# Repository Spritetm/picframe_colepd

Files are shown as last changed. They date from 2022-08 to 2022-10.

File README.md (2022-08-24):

* Workflow
Uploading:
- html/js: select image, crop, resize, upload to server
- upload php: use C program to convert to EPD.
  Spit out preview (?), add epd to database w/ timestamp

epd:
- Wake up
If Internet:
 * fetch index JSON file (contains OTA plus timestamps of last 10 images)
 * Update files to make internal store match 
 * Update list of image shows: set to 0 for new images
- Take list of image shows; get lowest show count; show newest image with that count.

Flash:
Other shit: 0x10000
OTA1: 0x150000
OTA2: 0x150000
left: 0x150000

img size 134464
11 images -> 10 150000

Case uses M3 inserts: height 4mm dia 5mm
Corresponding screws: M3*6mm

Colors:
- Grab picture in 'normal' situation (daylight, curtains, ...)
- Open in Gimp
- Image -> precision: 16-bit, linear
- Filters -> blur (to get rid of grain)
- Curve -> make darker colors a bit more dark (so it mixes more white in there, making end image lighter)
- Filters -> levels, select black level, select white level

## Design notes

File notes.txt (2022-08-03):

For PCB:
XR1151 - 800'ish mA, 65uA quiescent -> 3.5 year
ESP32C3 - need to test if works with same code, otherwise NP

Article:
Color Floyd-Steinberg is a PITA. Difference colors? LAB colors, euclidian thingy. That sucks,
pink white and blue-ish white is the same difference as red and blue. Initial modification:
multiply A and B differences (=hue difference) with sin(L). This makes those differences less
important. Great results. But WtF is up with the shitty 'official' way? Seems there's multiple
ways: latest and greatest is E2000. Actually not that much different than my hacky solution.

Non-linear color space: one pixel of (0,0,0) and one of (64,64,64) don't look the same 
(are not as bright) as two of (32,32,32). Luckily (linearized) RGB works.

Stucki dithering?

https://mathematica.stackexchange.com/questions/7483/how-to-calculate-mix-of-4-colors-defined-in-cielab-lab-model

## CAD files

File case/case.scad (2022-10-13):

/*
 * ----------------------------------------------------------------------------
 * "THE BEER-WARE LICENSE" (Revision 42):
 * Jeroen Domburg <jeroen@spritesmods.com> wrote this file. As long as you retain 
 * this notice you can do whatever you want with this stuff. If we meet some day, 
 * and you think this stuff is worth it, you can buy me a beer in return. 
 * ----------------------------------------------------------------------------
*/


$fs=0.2;

pcb_size=[155.5,130,1.6];
holes=[
    [7.5,7.5,0],
    [7.5,65,0],
    [7.5,130-7.5,0],
    [155.5-40.1,7.5,0],
    [155.5-7.5,65,0],
    [155.5-7.5,130-7.5,0],
    [155.5/2,130+5.3,0] //battery compartment screw
];
btns=[
    [64, 92.25, 0],
    [91.5, 92.25, 0]
];
btn_d=10;

//location of the battery terminals
bat_plus_pos=[24.5, 122, 0];
bat_min_pos=[131, 122, 0];
//Size of the pocket for the battery terminal solder points
bat_term_stickout=[3, 6, 1.3];
bat_term_size=[0.65, 12, 12.5];
bat_dia=15; //aa battery
eink_pcb_offset=[16.2, 16.9, 0];
eink_size=[125.4, 99.5, 0.95];
eink_vis_size=[114.9, 85.8, 0]; //visible area size
eink_vis_offset=[5.25, eink_size.y-eink_vis_size.y-4.6, 0];

pcb_center=eink_pcb_offset+eink_vis_offset+eink_vis_size/2;

mat_size=[145,120,3]; //size of actual mat
mat_cutout=[eink_vis_size.x+15, eink_vis_size.y+15,0]; //cutout for mat in case
mat_vis_extra=1; //how much mm more to show than the visible eink area

case_size=[170,143,24];
case_th=1.5;

screw_insert_d=5;
screw_insert_h=4;
screw_insert_post_d=7;
screw_hole_d=8.5;
screw_thread_hole_d=3.5;

tolerance=0.2;

support_d=2.0+tolerance;
support_pos=[0,-30,-6];
support_angle=[30,0,0];

render=2;

if (render==1) {
    intersection() {
        rotate([0,0,00]) union() {
            translate(-pcb_center) pcb();
            translate([0,0,pcb_size.z]) color("beige") mat();
            case_top();
            case_bottom();
            battery_lid();
        }
        translate([0,55,0])cube([200,1,40], center=true);
    }
} else if (render==2) {
    //translate(-pcb_center) pcb();
    //translate([0,0,pcb_size.z]) color("beige") mat();
    //case_top();
    case_bottom();
    //battery_lid();
} else if (render==3) {
    button("R");
    translate([10,10,0]) button("C");
}


module button(txt) {
    difference() {
        union() {
            cylinder(h=8, d=btn_d-tolerance*2);
            cylinder(h=2, d=btn_d+case_th*2);
            translate([-(case_th-tolerance*2)/2,0,0]) cube([(case_th-tolerance*2),btn_d/2+case_th,5]);
        }
        translate([0,0,-1]) cylinder(h=3.5, d=4.5);
        translate([-3,-3,7.5])linear_extrude(height = 1) {
            text(txt, font = "Liberation Sans:style=Bold",size=6);
        }
    }
}

module pcb() {
    difference() {
        cube(pcb_size);
        for (pos=holes) {
            translate(pos+[0,0,-1]) cylinder(h=pcb_size.z+2, d=3.2);
        }
    }
    //Eink
    translate(eink_pcb_offset) color("white") cube(eink_size+[0,0,pcb_size.z]);
    //eink visible area
    translate(eink_pcb_offset+eink_vis_offset) color("magenta") cube(eink_vis_size+[0,0,pcb_size.z+eink_size.z+0.1]);
    translate(bat_plus_pos-[bat_term_size.x/2, bat_term_size.y/2, bat_term_size.z]) cube(bat_term_size);
    translate(bat_min_pos-[bat_term_size.x/2, bat_term_size.y/2, bat_term_size.z]) cube(bat_term_size);
    translate(bat_plus_pos-[-2, 0, bat_dia/2]) rotate([0,90,0]) cylinder(d=bat_dia, h=100);
}

module chamfered_cutout(size) {
    difference() {
    translate([0,0,size.z/2]) cube(size+[size.z*2,size.z*2,tolerance*2], center=true);
        translate([-size.x/2,-size.y,0]) rotate([0,-45,0]) translate([-size.z*2,0,0]) cube([size.z*2, size.y*2, size.z*2]);
        translate([size.x/2,-size.y,0]) rotate([0,45,0]) translate([0,0,-tolerance*2])cube([size.z*2, size.y*2, size.z*2]);
        translate([-size.x,-size.y/2,0]) rotate([45,0,0]) translate([0,-size.z*2,0])cube([size.x*2, size.z*2, size.z*2]);
        translate([-size.x,size.y/2,0]) rotate([-45,0,0]) translate([0,0,-tolerance*2])cube([size.x*2, size.z*2, size.z*2]);
    }
}


//note: assuming the eink visible middle is at [0,0] and the top of the pcb at z=0
module mat() {
    difference() {
        translate([0,0,mat_size.z/2]) cube(mat_size, center=true);
        for (pos=holes) {
            translate(-pcb_center+pos+[0,0,-1]) cylinder(h=mat_size.z+2, d=screw_insert_post_d+tolerance*2);
        }
        //beveled hole
        translate([0,0,eink_size.z-tolerance])chamfered_cutout(eink_vis_size+[mat_vis_extra*2,mat_vis_extra*2,mat_size.z]);
        //eink plate hole
        translate(-pcb_center+eink_pcb_offset-[1, 1, tolerance]) cube(eink_size+[1, 1, tolerance]*2);
        //cutouts for battery contact solder things
        translate(-pcb_center+bat_plus_pos-[bat_term_stickout.x/2, bat_term_stickout.y/2, pcb_size.z]) cube(bat_term_stickout+[0,0,pcb_size.z]);
        translate(-pcb_center+bat_min_pos-[bat_term_stickout.x/2, bat_term_stickout.y/2, tolerance]) cube(bat_term_stickout+[0,0,tolerance]);
    }
}


module case_top() {
    difference() {
        intersection() {
            case();
            translate([-100,-100,-case_th+tolerance*2]) cube([200,200,20]);
        }
        //lip
        translate([-case_size.x/2+case_th/2-tolerance/2, -case_size.y/2+case_th/2-tolerance/2, -case_size.z+tolerance*2]) cube(case_size-[case_th-tolerance,case_th-tolerance,0]);
    }
}


module case_bot_fancy(pullback) {
    edge_off=case_th*2;
    h=bat_dia+case_th*2;
    difference() {
        //square case
        translate([0,0,bat_dia/2+case_th-pullback]) cube([case_size.x-pullback*2,case_size.y-pullback*2,bat_dia+edge_off], center=true);
        //beveled main
        translate([-100, pcb_center.y-bat_plus_pos.y+bat_dia/2, h-pullback]) rotate([-5,0,0]) cube([200,200,20]);
        //beveled at battery
        translate([-100, pcb_center.y-bat_plus_pos.y-bat_dia/2, h-pullback]) rotate([30,0,0]) translate([0,-200,0]) cube([200,200,20]);
        //beveled edges
        translate([case_size.x/2,-case_size.y/2-tolerance,edge_off-pullback]) rotate([0,50,0]) translate([-100,-tolerance*2,0]) cube([100,case_size.y+tolerance*4,case_size.z,]);
        translate([-case_size.x/2,case_size.y/2-tolerance,edge_off-pullback]) rotate([0,50,180]) translate([-100,-tolerance*2,0]) cube([100,case_size.y+tolerance*4,case_size.z,]);

        //lip
        if (pullback==0) difference() {
            translate([0,0,case_th/2+tolerance/2]) cube([case_size.x,case_size.y,case_th+tolerance], center=true);
            translate([0,0,case_th/2+tolerance/2]) cube([case_size.x-case_th,case_size.y-case_th,case_th+tolerance], center=true);
        }
    }
}

module battery_lid_cutout(pullback) {
    translate(-pcb_center) {
        translate([bat_plus_pos.x-bat_term_size.x/2-pullback,bat_min_pos.y-bat_dia/2-pullback,-20+tolerance*(case_th-pullback)]) cube((bat_min_pos-bat_plus_pos)+[bat_term_size.x+pullback*2,50,20]);
        
    }
}


module battery_lid() {
    difference() {
        intersection() {
            difference() {
                //outer case
                rotate([180,0,0]) case_bot_fancy(0);
                //cut out screwholes
                for (pos=holes) {
                    translate(-pcb_center+pos+[0,0,-50-case_th]) cylinder(h=50, d=screw_hole_d);
                    translate(-pcb_center+pos+[0,0,-50+tolerance]) cylinder(h=50, d=screw_thread_hole_d);
                }
            }
            //cut out battery lid itself and half of the inner wall
            battery_lid_cutout(case_th/2-tolerance);
        }
        difference() {
            rotate([180,0,0]) case_bot_fancy(case_th/2-tolerance);
            battery_lid_cutout(-tolerance);
        }
        difference() {
            //inner case
            rotate([180,0,0]) case_bot_fancy(case_th);
            //cut out screwholes
            for (pos=holes) {
                translate(-pcb_center+pos+[0,0,-50]) cylinder(h=50, d=screw_hole_d+case_th*2);
            }
    translate(-pcb_center+[bat_plus_pos.x-bat_term_size.x,bat_min_pos.y+bat_dia/2,-20+tolerance]) cube((bat_min_pos-bat_plus_pos)+[bat_term_size.x*2,case_th,20]);

        }
    }
    
}

module support(pullback) {
    translate(support_pos) rotate(-support_angle+[270,0,0]) translate([0,0,-pullback]) cylinder(h=90,d=support_d+pullback*2);
}

//support(0);
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

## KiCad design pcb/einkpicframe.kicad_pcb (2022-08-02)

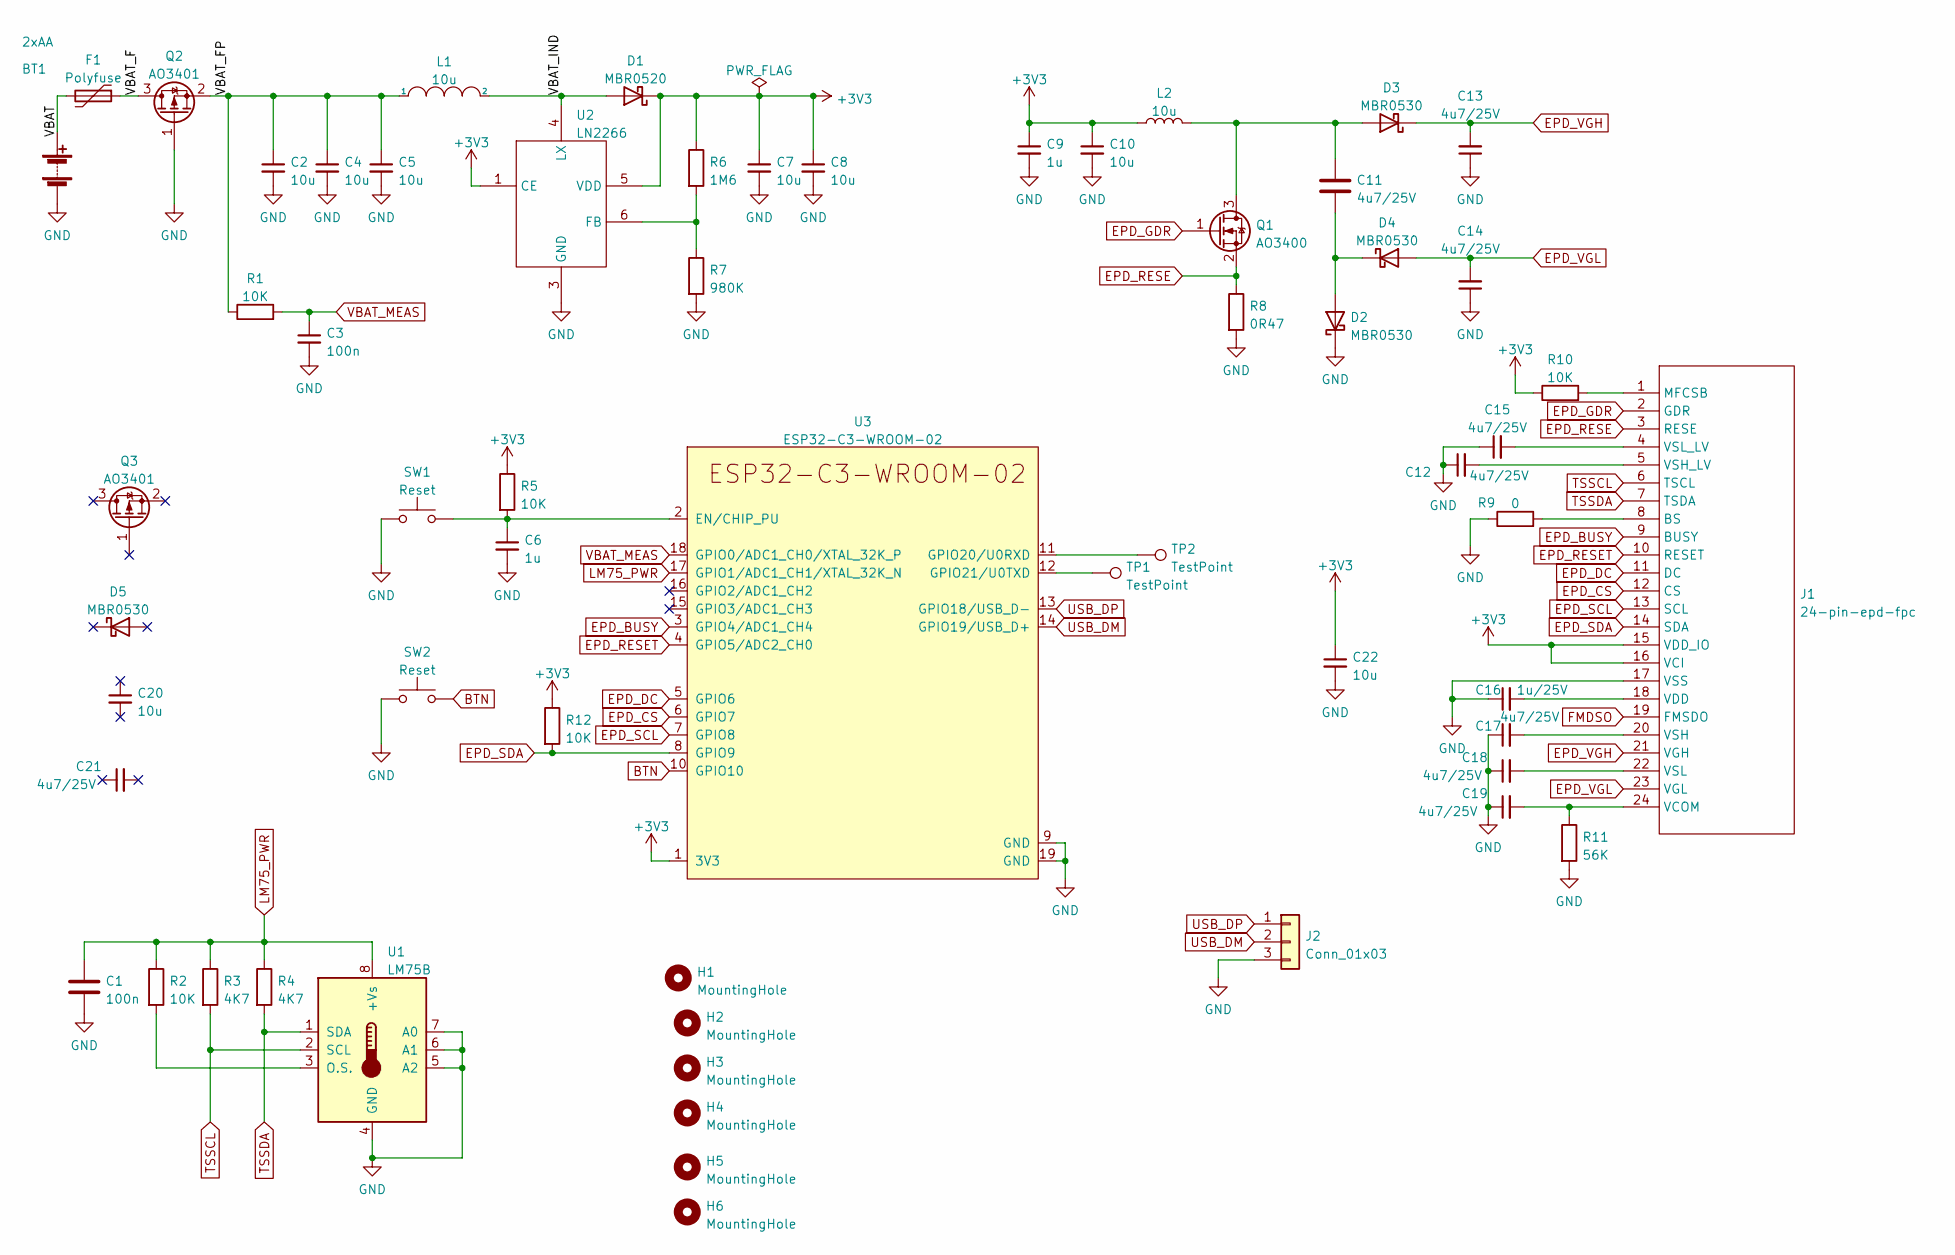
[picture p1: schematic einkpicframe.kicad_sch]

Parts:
BT1: 2xAA; 2xaa_pcb_conn
C1, C3: 100n; C_0603_1608Metric
C2, C4, C5, C7, C8, C10, C20, C22: 10u; C_0805_2012Metric
C6, C9: 1u; C_0603_1608Metric
C11, C12, C13, C14, C15, C17, C18, C19, C21: 4u7/25V; C_0603_1608Metric
C16: 1u/25V; C_0603_1608Metric
D1: MBR0520; D_SOD-123
D2, D3, D4, D5: MBR0530; D_SOD-123
F1: Polyfuse; Fuse_0805_2012Metric
H1, H2, H3, H4, H5, H6: MountingHole; MountingHole_3.2mm_M3_ISO14580
J1: 24-pin-epd-fpc; Hirose_FH12-24S-0.5SH_1x24-1MP_P0.50mm_Horizontal_reverse
J2: Conn_01x03; PinHeader_1x03_P2.54mm_Horizontal
L1, L2: 10u; IND_WHC0630
Q1: AO3400; SOT-23
Q2, Q3: AO3401; SOT-23W_Handsoldering
R1, R2, R5, R10, R12: 10K; R_0603_1608Metric
R3, R4: 4K7; R_0603_1608Metric
R6: 1M6; R_0603_1608Metric
R7: 980K; R_0603_1608Metric
R8: 0R47; R_0603_1608Metric
R9: 0; R_0603_1608Metric
R11: 56K; R_0603_1608Metric
SW1, SW2: Reset; SW_SPST_B3S-1000
TP1, TP2: TestPoint; TestPoint_Pad_1.5x1.5mm
U1: LM75B; TSSOP-8_3x3mm_P0.65mm
U2: LN2266; SOT-23-6
U3: ESP32-C3-WROOM-02

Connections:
+3V3: C7.1, C8.1, C9.1, C10.1, C22.1, D1.1 (K), J1.15 (VDD_IO), J1.16 (VCI), L2.1, R5.1, R6.1, R10.1, R12.1, U2.1 (CE), U2.5 (VDD), U3.1 (3V3)
/VBAT: BT1.1 (+), F1.2
/VBAT_F: F1.1, Q2.3 (D)
/VBAT_FP: C2.1, C4.1, C5.1, L1.1, Q2.2 (S), R1.1
/VBAT_IND: D1.2 (A), L1.2, U2.4 (LX)
BTN: SW2.2, U3.10 (GPIO10)
EPD_BUSY: J1.9 (BUSY), U3.3 (GPIO4/ADC1_CH4)
EPD_CS: J1.12 (CS), U3.6 (GPIO7)
EPD_DC: J1.11 (DC), U3.5 (GPIO6)
EPD_GDR: J1.2 (GDR), Q1.1 (G)
EPD_RESE: J1.3 (RESE), Q1.2 (S), R8.1
EPD_RESET: J1.10 (RESET), U3.4 (GPIO5/ADC2_CH0)
EPD_SCL: J1.13 (SCL), U3.7 (GPIO8)
EPD_SDA: J1.14 (SDA), R12.2, U3.8 (GPIO9)
EPD_VGH: C13.2, D3.1 (K), J1.21 (VGH)
EPD_VGL: C14.2, D4.2 (A), J1.23 (VGL)
FMDSO: J1.19 (FMSDO)
GND: BT1.2 (-), C1.2, C2.2, C3.2, C4.2, C5.2, C6.2, C7.2, C8.2, C9.2, C10.2, C12.1, C13.1, C14.1, C15.1, C16.1, C17.1, C18.1, C19.1, C22.2, D2.1 (K), J1.17 (VSS), J2.3, Q2.1 (G), R7.2, R8.2, R9.1, R11.2, SW1.1, SW2.1, U1.4 (GND), U1.5 (A2), U1.6 (A1), U1.7 (A0), U2.3 (GND), U3.9 (GND), U3.19 (GND)
LM75_PWR: C1.1, R2.1, R3.1, R4.1, U1.8 (+Vs), U3.17 (GPIO1/ADC1_CH1/XTAL_32K_N)
unnamed: C6.1, R5.2, SW1.2, U3.2 (EN/CHIP_PU)
unnamed: C11.1, D3.2 (A), L2.2, Q1.3 (D)
unnamed: C11.2, D2.2 (A), D4.1 (K)
unnamed: C12.2, J1.5 (VSH_LV)
unnamed: C15.2, J1.4 (VSL_LV)
unnamed: C16.2, J1.18 (VDD)
unnamed: C17.2, J1.20 (VSH)
unnamed: C18.2, J1.22 (VSL)
unnamed: C19.2, J1.24 (VCOM), R11.1
unnamed: J1.1 (MFCSB), R10.2
unnamed: J1.8 (BS), R9.2
unnamed: R2.2, U1.3 (O.S.)
unnamed: R6.2, R7.1, U2.6 (FB)
unnamed: TP2.1, U3.11 (GPIO20/U0RXD)
unnamed: TP1.1, U3.12 (GPIO21/U0TXD)
TSSCL: J1.6 (TSCL), R3.2, U1.2 (SCL)
TSSDA: J1.7 (TSDA), R4.2, U1.1 (SDA)
USB_DM: J2.2, U3.14 (GPIO19/USB_D+)
USB_DP: J2.1, U3.13 (GPIO18/USB_D-)
VBAT_MEAS: C3.1, R1.2, U3.18 (GPIO0/ADC1_CH0/XTAL_32K_P)

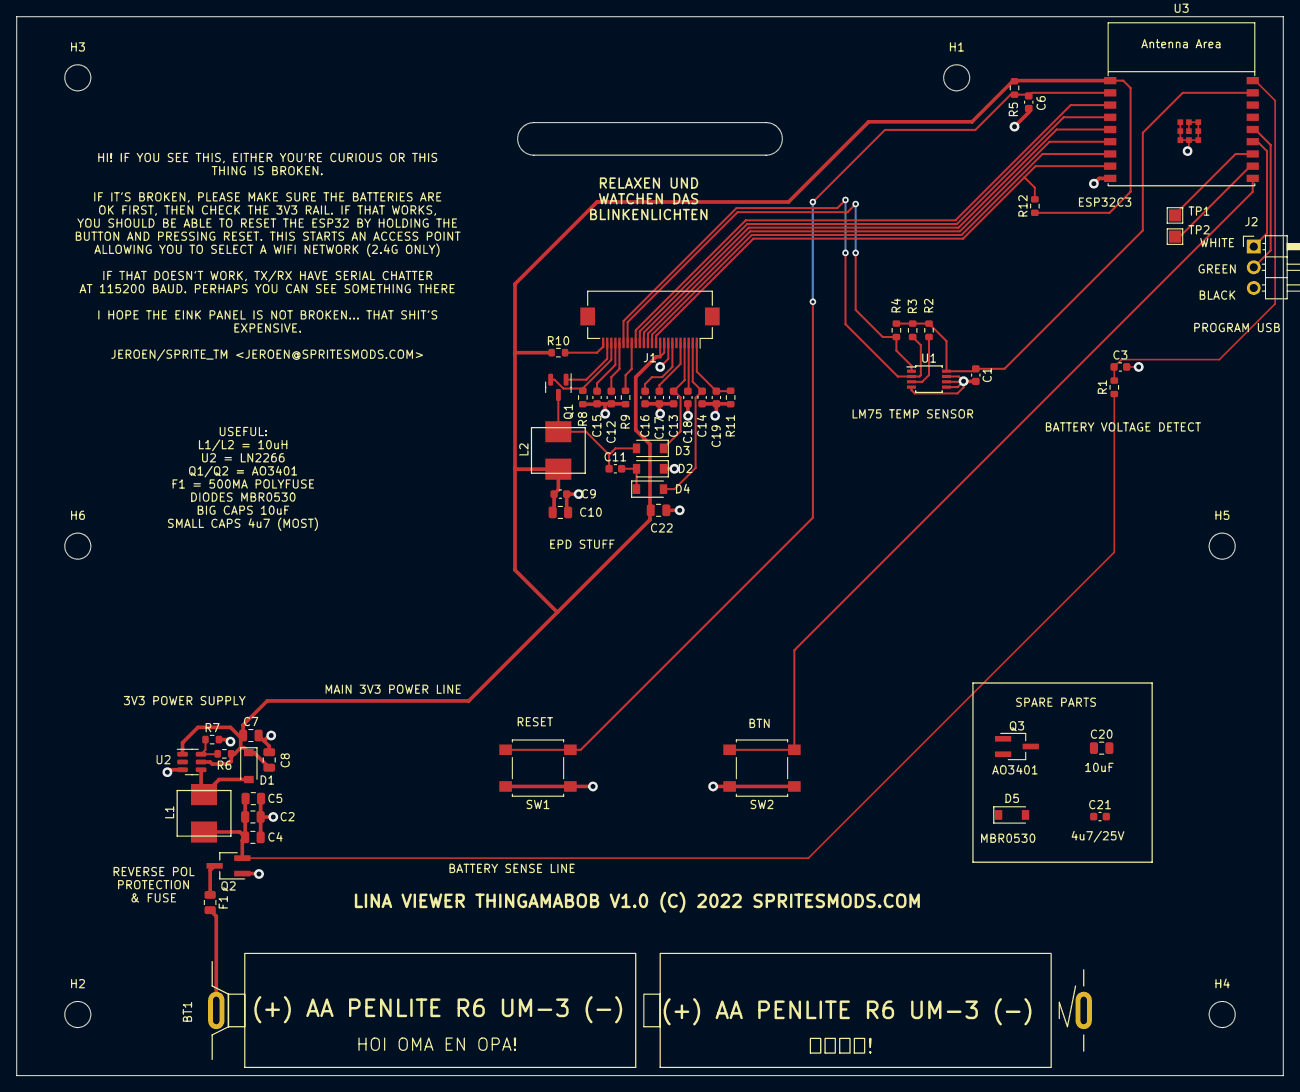
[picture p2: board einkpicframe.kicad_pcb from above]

Board: 2 copper layers, 155.5 x 130.0 mm, 61 parts (0 on the bottom side), 38 nets.

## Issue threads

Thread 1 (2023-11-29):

No output from display

hamishfagg, 2023-11-29:
Hi there,
I'm attempting to build one of these, thank you so much for the design!

I had the boards made by JLC, and I have the firmware working fine, downloading images etc. But the screen never flickers or displays anything - just stays white.
Do you have any idea what this could be? The logs from the firmware are below, in case the gpio output is of use:

```
I (3753) sync: Sync done.
I (4113) main: Displaying img id 8 from slot 7
I (4113) gpio: GPIO[5]| InputEn: 0| OutputEn: 1| OpenDrain: 0| Pullup: 0| Pulldown: 0| Intr:0
I (4113) gpio: GPIO[6]| InputEn: 0| OutputEn: 1| OpenDrain: 0| Pullup: 0| Pulldown: 0| Intr:0
I (4123) gpio: GPIO[4]| InputEn: 1| OutputEn: 0| OpenDrain: 0| Pullup: 1| Pulldown: 0| Intr:0
I (5433) epd: Displayed image.
I (5433) gpio: GPIO[5]| InputEn: 0| OutputEn: 1| OpenDrain: 0| Pullup: 0| Pulldown: 0| Intr:0
I (5443) gpio: GPIO[6]| InputEn: 0| OutputEn: 1| OpenDrain: 0| Pullup: 0| Pulldown: 0| Intr:0
I (5443) gpio: GPIO[7]| InputEn: 0| OutputEn: 1| OpenDrain: 0| Pullup: 0| Pulldown: 0| Intr:0
I (5453) gpio: GPIO[8]| InputEn: 0| OutputEn: 1| OpenDrain: 0| Pullup: 0| Pulldown: 0| Intr:0
I (5463) gpio: GPIO[9]| InputEn: 0| OutputEn: 1| OpenDrain: 0| Pullup: 0| Pulldown: 0| Intr:0
I (5473) main: Going to sleep.
```

There's output from the ESP32 on SCL and SDA when its writing image data, and the screen has 3.3V where it should, so Im not sure what's wrong

Spritetm, 2023-11-30:
That could be a lot of things, and generally the screen doesn't give much feedback. The only line back is the BUSY line; can you check if that ever goes to 0 for a few ms, or does it stay at 1?

hamishfagg, 2023-12-01:
Well this is embarrassing - I took another look at the PCB and realised I had got the wrong ribbon connectors installed on the PCB, bottom contacts instead of top.
So I've ordered the right ones, I'll close this assuming it'll work when the screen is actually connected lol

Spritetm, 2023-12-01:
That'll do it indeed :) if you still run into issues (and/or if you succesfully built yours!) feel free to open a new issue or send me a message.

Closed 2023-12-01.

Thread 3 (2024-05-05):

spi_flash_mmap_handle_t problem when building

donutbrew, 2024-05-05:
I get the following error when trying to flash the ESP32 using ESP-IDF 5.2 and command `idf.py  flash -p COM6`:

```
C:/Users/oldgreg/picframe_colepd/firmware/main/main.c: In function 'app_main':
C:/Users/oldgreg/picframe_colepd/firmware/main/main.c:88:9: error: unknown type name 'spi_flash_mmap_handle_t'
   88 |         spi_flash_mmap_handle_t mmap_handle;
      |         ^~~~~~~~~~~~~~~~~~~~~~~
C:/Users/oldgreg/picframe_colepd/firmware/main/main.c:90:68: error: 'SPI_FLASH_MMAP_DATA' undeclared (first use in this function)
   90 |         esp_partition_mmap(part, 0, IMG_SIZE_BYTES*IMG_SLOT_COUNT, SPI_FLASH_MMAP_DATA, (const void**)&images, &mmap_handle);
      |                                                                    ^~~~~~~~~~~~~~~~~~~
C:/Users/oldgreg/picframe_colepd/firmware/main/main.c:90:68: note: each undeclared identifier is reported only once for each function it appears in
C:/Users/oldgreg/picframe_colepd/firmware/main/main.c:90:112: warning: passing argument 6 of 'esp_partition_mmap' from incompatible pointer type [-Wincompatible-pointer-types]
   90 |         esp_partition_mmap(part, 0, IMG_SIZE_BYTES*IMG_SLOT_COUNT, SPI_FLASH_MMAP_DATA, (const void**)&images, &mmap_handle);
      |                                                                                                                ^~~~~~~~~~~~
      |
      |                                                                                                                int *
In file included from C:/Users/oldgreg/picframe_colepd/firmware/main/main.c:23:
C:/Espressif5/frameworks/esp-idf-v5.2/components/esp_partition/include/esp_partition.h:380:81: note: expected 'esp_partition_mmap_handle_t *' {aka 'long unsigned int *'} but argument is of type 'int *'
  380 |                              const void** out_ptr, esp_partition_mmap_handle_t* out_handle);
      |                                                    ~~~~~~~~~~~~~~~~~~~~~~~~~~~~~^~~~~~~~~~
ninja: build stopped: subcommand failed.
ninja failed with exit code 1, output of the command is in the C:\Users\oldgreg\picframe_colepd\firmware\build\log\idf_py_stderr_output_23720 and C:\Users\oldgreg\picframe_colepd\firmware\build\log\idf_py_stdout_output_23720
```

Again, any help you can give is much appreciated!

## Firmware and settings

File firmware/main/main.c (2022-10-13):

/*
 * ----------------------------------------------------------------------------
 * "THE BEER-WARE LICENSE" (Revision 42):
 * Jeroen Domburg <jeroen@spritesmods.com> wrote this file. As long as you retain 
 * this notice you can do whatever you want with this stuff. If we meet some day, 
 * and you think this stuff is worth it, you can buy me a beer in return. 
 * ----------------------------------------------------------------------------
*/

#include <stdio.h>
#include <stdlib.h>
#include <string.h>
#include "freertos/FreeRTOS.h"
#include "freertos/task.h"
#include "esp_system.h"
#include "esp_timer.h"
#include "esp_log.h"
#include "driver/gpio.h"
#include "esp_wifi.h"
#include "lwip/ip_addr.h"
#include "wifi_manager.h"
#include <assert.h>
#include "esp_partition.h"
#include "esp_http_client.h"
#include "nvs.h"
#include "epd.h"
#include "epd_flash_image.h"
#include "esp_sleep.h"
#include "esp_timer.h"
#include "sync.h"
#include "io.h"
#include "nvs_flash.h"
#include "esp_ota_ops.h"

static const char *TAG="main";

SemaphoreHandle_t connect_sema;

void cb_connection_ok(void *pvParameter){
	ip_event_got_ip_t* param = (ip_event_got_ip_t*)pvParameter;

	/* transform IP to human readable string */
	char str_ip[16];
	esp_ip4addr_ntoa(&param->ip_info.ip, str_ip, IP4ADDR_STRLEN_MAX);

	ESP_LOGI(TAG, "I have a connection and my IP is %s!", str_ip);
	xSemaphoreGive(connect_sema);
}

void shutdown_callback(void *arg) {
	ESP_LOGW(TAG, "Alive for too long! Sleeping.");
	esp_sleep_enable_timer_wakeup(60*60*1000ULL*1000ULL);
	esp_deep_sleep_start();
}


void app_main(void) {
	_Static_assert((sizeof(flash_image_t) == IMG_SIZE_BYTES), "flash_image_t not right size");
	connect_sema=xSemaphoreCreateBinary();
	io_init();
	int icon=ICON_NONE;

	//make sure we shut down after 10 mins guaranteed
	esp_timer_create_args_t config={
		.callback=shutdown_callback,
		.name="shutdown",
		.skip_unhandled_events=true
	};
	esp_timer_handle_t handle;
	esp_timer_create(&config, &handle);
	esp_timer_start_periodic(handle, 10*60*1000ULL*1000ULL);

	//Initialize NVS
	esp_err_t err = nvs_flash_init();
	if (err == ESP_ERR_NVS_NO_FREE_PAGES || err == ESP_ERR_NVS_NEW_VERSION_FOUND) {
		//NVS partition was truncated and needs to be erased. 
		ESP_ERROR_CHECK(nvs_flash_erase());
		err = nvs_flash_init(); //Retry nvs_flash_init
	}
	ESP_ERROR_CHECK(err);

	//get nvs handle
	nvs_handle_t nvs;
	nvs_open("epd", NVS_READWRITE, &nvs);

	//map image partition, we'll need it later
	const flash_image_t *images=NULL;
	spi_flash_mmap_handle_t mmap_handle;
	const esp_partition_t *part=esp_partition_find_first(123, 0, NULL);
	esp_partition_mmap(part, 0, IMG_SIZE_BYTES*IMG_SLOT_COUNT, SPI_FLASH_MMAP_DATA, (const void**)&images, &mmap_handle);

	//see if we still have enough juice to go online
	int bat=io_get_battery_mv();
	int32_t bat_empty_thr=2250;
	ESP_LOGI(TAG, "Battery at %d mV before going online...", bat);

	if (bat<bat_empty_thr) {
		icon=ICON_BAT_EMPTY;
	} else {
		//start the wifi manager
		wifi_manager_start();
		wifi_manager_set_callback(WM_EVENT_STA_GOT_IP, &cb_connection_ok);

		if (io_get_btn()) {
			vTaskDelay(pdMS_TO_TICKS(200));
			wifi_manager_send_message(WM_ORDER_DISCONNECT_STA, NULL);
			vTaskDelay(pdMS_TO_TICKS(200));
			wifi_manager_send_message(WM_ORDER_START_AP, NULL);
			vTaskDelay(pdMS_TO_TICKS(200));
			wifi_manager_send_message(WM_ORDER_START_HTTP_SERVER, NULL);
			vTaskDelay(pdMS_TO_TICKS(200));
			wifi_manager_send_message(WM_ORDER_START_DNS_SERVICE, NULL);
		}
		//wait for connection
		ESP_LOGI(TAG, "Waiting for connection...x");
		int can_connect=xSemaphoreTake(connect_sema, pdMS_TO_TICKS(30*1000));
		int bat=io_get_battery_mv();
		ESP_LOGI(TAG, "Battery at %d mV after WiFi init", bat);
		if (bat<bat_empty_thr) {
			icon=ICON_BAT_EMPTY;
		} else {
			if (can_connect) {
				//We have a WiFi connection.
				err=picframe_sync(images, part);
				if (err==ESP_OK) esp_ota_mark_app_valid_cancel_rollback();
				if (err!=ESP_OK) icon=ICON_SERVER;
			} else {
				icon=ICON_WIFI;
				//No connection, mayhaps we're in config mode?
				//If so, wait for a few minutes for the user to do its thing in the
				//wifi manager UI. We break out either when we have a sta connection or
				//if the mode is not apsta/ap anymore.
				int wifi_timeout_sec=3*60;
				do {
					wifi_mode_t mode;
					esp_wifi_get_mode(&mode);
					if (mode==WIFI_MODE_STA) break;

					can_connect=xSemaphoreTake(connect_sema, pdMS_TO_TICKS(1*1000));
					if (can_connect) break;

					wifi_timeout_sec--;
					if (wifi_timeout_sec==0) break;
					ESP_LOGI(TAG, "Delaying shutdown as we're in AP/APSTA mode...");
				} while(1);

				if (can_connect) {
					err=picframe_sync(images, part);
					if (err==ESP_OK) esp_ota_mark_app_valid_cancel_rollback();
					if (err!=ESP_OK) icon=ICON_SERVER; else icon=ICON_NONE;
				}
			}
		}

		//Assume we're entirely done with WiFi.
		wifi_manager_destroy();
		vTaskDelay(pdMS_TO_TICKS(200)); //needed?
		esp_wifi_stop();
	}

	//Grab cur_img and img_shows data from NVS
	int16_t curr_img[IMG_SLOT_COUNT];
	int16_t img_shows[IMG_SLOT_COUNT]={0};
	for (int i=0; i<IMG_SLOT_COUNT; i++) curr_img[i]=-1; //default to invalid
	size_t len=IMG_SLOT_COUNT*sizeof(uint16_t);
	nvs_get_blob(nvs, "curr_img", curr_img, &len);
	len=IMG_SLOT_COUNT*sizeof(uint16_t);
	nvs_get_blob(nvs, "img_shows", img_shows, &len);

	//Find the image that is valid with the highest ID and lowest count
	int img=0;
	for (int i=1; i<IMG_SLOT_COUNT; i++) {
		if (curr_img[i]==-1) continue; //invalid
		if (img_shows[i]<img_shows[img]) {
			img=i;
		} else if (img_shows[i]==img_shows[img]) {
			if (curr_img[i]>curr_img[img]) img=i;
		}
	}
	
	//Show image we found, if any
	if (curr_img[img]!=-1) {
		img_shows[img]++;
		nvs_set_blob(nvs, "img_shows", img_shows, IMG_SLOT_COUNT*sizeof(uint16_t));
		
		ESP_LOGI(TAG, "Displaying img id %d from slot %d", curr_img[img], img);
		epd_send(images[img].data, icon);
		epd_shutdown();
	}

	ESP_LOGI(TAG, "Going to sleep.");
	//Set timezone
	char tz[32];
	len=sizeof(tz);
	if (nvs_get_str(nvs, "tz", tz, &len)==ESP_OK) {
		setenv("TZ", tz, 1);
		tzset();
	}
	//Figure out when to wake.
	int32_t updhour=0;
	nvs_get_i32(nvs, "upd_hour", &updhour);
	struct tm tm;
	time_t now=time(NULL);
	localtime_r(&now, &tm);
	ESP_LOGI(TAG, "Now is %d:%02d, sleeping till %ld:00", tm.tm_hour, tm.tm_min, updhour);
	tm.tm_hour=updhour;
	tm.tm_min=0;
	time_t wake=mktime(&tm);
	int64_t sleep_sec=wake-time(NULL);
	//Make sure this is in the future. We can wake up a bit before the wake time, and without
	//this, it would sleep only a short while until the actual wake time.
	while (sleep_sec<(10*60)) sleep_sec+=(24*60*60);

	if (icon==ICON_BAT_EMPTY) {
		//Sleep forever.
		ESP_LOGI(TAG, "Low battery, so sleeping forever.");
		esp_deep_sleep_start();
	}
	//Zzzzz....
	ESP_LOGI(TAG, "Sleeping %lld sec", sleep_sec);
	esp_sleep_enable_timer_wakeup(sleep_sec*1000ULL*1000ULL);
	vTaskDelay(pdMS_TO_TICKS(100));
	esp_deep_sleep_start();
}

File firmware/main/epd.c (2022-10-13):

/*
 * ----------------------------------------------------------------------------
 * "THE BEER-WARE LICENSE" (Revision 42):
 * Jeroen Domburg <jeroen@spritesmods.com> wrote this file. As long as you retain 
 * this notice you can do whatever you want with this stuff. If we meet some day, 
 * and you think this stuff is worth it, you can buy me a beer in return. 
 * ----------------------------------------------------------------------------
*/


#include <stdio.h>
#include <stdlib.h>
#include <string.h>
#include "freertos/FreeRTOS.h"
#include "freertos/task.h"
#include "esp_log.h"
#include "driver/spi_master.h"
#include "driver/gpio.h"
#include "esp_timer.h"

#ifdef HSPI_HOST
//Waveshare ESP32 board
#define EPD_HOST	HSPI_HOST
#define PIN_NUM_BUSY 25
#define PIN_NUM_MOSI 14
#define PIN_NUM_CLK	 13
#define PIN_NUM_CS	 15
#define PIN_NUM_RST	 26
#define PIN_NUM_DC	 27
#else
//Actual picframe_epd board.
#define EPD_HOST	SPI2_HOST
#define PIN_NUM_BUSY 4
#define PIN_NUM_MOSI 9
#define PIN_NUM_CLK	 8
#define PIN_NUM_CS	 7
#define PIN_NUM_RST	 5
#define PIN_NUM_DC	 6
#endif


//To speed up transfers, every SPI transfer sends a bunch of lines. This define specifies how many. More means more memory use,
//but less overhead for setting up / finishing transfers. Make sure 240 is dividable by this.
#define PARALLEL_LINES 16

static const char *TAG="epd";

/*
 The EPD needs a bunch of command/argument values to be initialized. They are stored in this struct.
*/
typedef struct {
	uint8_t cmd;
	uint8_t data[16];
	uint8_t databytes; //No of data in data; bit 7 = delay after set; 0xFF = end of cmds.
} epd_init_cmd_t;
#define INIT_DATA_WAIT 0x80

static const epd_init_cmd_t epd_init_cmds[]={
	{0x00, {0xef, 0x08}, 2},
	{0x01, {0x37, 0x00, 0x23, 0x23}, 4},
	{0x03, {0x00}, 1},
	{0x06, {0xC7, 0xC7, 0x1D}, 3},
	{0x30, {0x39}, 1},
	{0x41, {0x00}, 1},
	{0x50, {0x37}, 1},
	{0x60, {0x22}, 1},
	{0x61, {0x02, 0x58, 0x01, 0xC0}, 4},
	{0xE3, {0xAA}, 1 | INIT_DATA_WAIT},
	{0x50, {0x37}, 1},
	{0, {0}, 0xFF}
};

/* Send a command to the EPD. Uses spi_device_polling_transmit, which waits
 * until the transfer is complete.
 */
static void epd_cmd(spi_device_handle_t spi, const uint8_t cmd) {
	esp_err_t ret;
	spi_transaction_t t;
	memset(&t, 0, sizeof(t));		//Zero out the transaction
	t.length=8;						//Command is 8 bits
	t.tx_buffer=&cmd;				//The data is the cmd itself
	t.user=(void*)0;				//D/C needs to be set to 0
	ret=spi_device_polling_transmit(spi, &t);  //Transmit!
	assert(ret==ESP_OK);			//Should have had no issues.
}

/* Send data to the EPD. Uses spi_device_polling_transmit, which waits until the
 * transfer is complete.
 */
static void epd_data(spi_device_handle_t spi, const uint8_t *data, int len) {
	esp_err_t ret;
	spi_transaction_t t;
	if (len==0) return;				//no need to send anything
	memset(&t, 0, sizeof(t));		//Zero out the transaction
	t.length=len*8;					//Len is in bytes, transaction length is in bits.
	t.tx_buffer=data;				//Data
	t.user=(void*)1;				//D/C needs to be set to 1
	ret=spi_device_polling_transmit(spi, &t);  //Transmit!
	assert(ret==ESP_OK);			//Should have had no issues.
}

//This function is called (in irq context!) just before a transmission starts. It will
//set the D/C line to the value indicated in the user field.
static void epd_spi_pre_transfer_callback(spi_transaction_t *t) {
	int dc=(int)t->user;
	gpio_set_level(PIN_NUM_DC, dc);
}

//Wait for the EPD to not be busy anymore
static void wait_busy(int val, int timeout_ms) {
	int64_t tout=esp_timer_get_time()+timeout_ms*1000;
	while(gpio_get_level(PIN_NUM_BUSY)!=val) {
		vTaskDelay(2);
		if (esp_timer_get_time()>tout) {
			ESP_LOGE(TAG, "Timeout on waiting for busy to go %s!", val?"high":"low");
			return;
		}
	}
}

//Initialize the display
static void epd_init(spi_device_handle_t spi) {
	int cmd=0;

	const gpio_config_t cfg[2]={
		{
			.pin_bit_mask=(1<<PIN_NUM_DC)|(1<<PIN_NUM_RST),
			.mode=GPIO_MODE_OUTPUT
		}, {
			.pin_bit_mask=(1<<PIN_NUM_BUSY),
			.mode=GPIO_MODE_INPUT,
			.pull_up_en=GPIO_PULLUP_ENABLE
		}
	};
	gpio_config(&cfg[0]);
	gpio_config(&cfg[1]);

	//Initialize non-SPI GPIOs
	gpio_set_direction(PIN_NUM_DC, GPIO_MODE_OUTPUT);
	gpio_set_direction(PIN_NUM_RST, GPIO_MODE_OUTPUT);
	gpio_set_direction(PIN_NUM_BUSY, GPIO_MODE_INPUT);

	//Reset the display
	gpio_set_level(PIN_NUM_RST, 0);
	vTaskDelay(pdMS_TO_TICKS(10));
	gpio_set_level(PIN_NUM_RST, 1);
	vTaskDelay(pdMS_TO_TICKS(100));

	//wait for not busy
	wait_busy(1, 1000);

	//Send all the commands
	while (epd_init_cmds[cmd].databytes!=0xff) {
		epd_cmd(spi, epd_init_cmds[cmd].cmd);
		uint8_t data[16];
		memcpy(data, epd_init_cmds[cmd].data, 16);
		epd_data(spi, data, epd_init_cmds[cmd].databytes&0x1F);
		if (epd_init_cmds[cmd].databytes&0x80) {
			vTaskDelay(pdMS_TO_TICKS(100));
		}
		cmd++;
	}
}

extern const uint8_t icons_bmp_start[] asm("_binary_icons_bmp_start");

spi_device_handle_t spi;

void epd_send(const uint8_t *epddata, int icon) {
	gpio_hold_dis(PIN_NUM_CS);
	gpio_hold_dis(PIN_NUM_RST);

	/* initialize epd */
	esp_err_t ret;
	spi_bus_config_t buscfg={
		.miso_io_num=-1,
		.mosi_io_num=PIN_NUM_MOSI,
		.sclk_io_num=PIN_NUM_CLK,
		.quadwp_io_num=-1,
		.quadhd_io_num=-1,
		.max_transfer_sz=PARALLEL_LINES*600/2+8
	};
	spi_device_interface_config_t devcfg={
		.clock_speed_hz=1*1000*1000,			//Clock out at 10 MHz
		.mode=0,								//SPI mode 0
		.spics_io_num=PIN_NUM_CS,				//CS pin
		.queue_size=7,							//We want to be able to queue 7 transactions at a time
		.pre_cb=epd_spi_pre_transfer_callback,	//Specify pre-transfer callback to handle D/C line
	};
	//Initialize the SPI bus
	ret=spi_bus_initialize(EPD_HOST, &buscfg, SPI_DMA_CH_AUTO);
	ESP_ERROR_CHECK(ret);
	//Attach the EPD to the SPI bus
	ret=spi_bus_add_device(EPD_HOST, &devcfg, &spi);
	ESP_ERROR_CHECK(ret);
	//Initialize the EPD
	epd_init(spi);
	
	epd_cmd(spi, 0x61);
	uint8_t data[4]={0x02, 0x58, 0x01, 0xC0};
	epd_data(spi, data, 4);
	epd_cmd(spi, 0x10);
	int bmp_pix_start=icons_bmp_start[0xa]+(icons_bmp_start[0xb]<<8); //actually header is 32-bit... care.
	//ESP_LOGI(TAG, "bmp starts at 0x%X", bmp_pix_start);
	for (int y=0; y<448; y++) {
		uint8_t buf[300];
		memcpy(buf, &epddata[y*300], 300);
		if (icon!=0 && y<32) {
			//the bmp is a file with 4-bit info. Each icon is 32x32 pixels (aka 32x16 bytes)
			memcpy(buf, &icons_bmp_start[bmp_pix_start+y*16+(icon-1)*(16*32)], 16);
		}
		epd_data(spi, buf, 300);
	}
	epd_cmd(spi, 0x4);
	wait_busy(1, 30000);
	epd_cmd(spi, 0x12);
	wait_busy(1, 30000);
	epd_cmd(spi, 0x2);
	wait_busy(1, 30000);
	ESP_LOGI(TAG, "Displayed image.");
}
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

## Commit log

2022-06-20 Move firmware to firmware dir
    [partitions.csv]
2022-07-31 Update to pcb
2022-07-31 Add case design
    [case.scad]
2022-07-31 do not save stl files
2022-08-01 Clean up firmware
    [partitions.csv]
2022-08-01 Switch wifi manager branch
2022-08-02 switch to own branch of wifi-manager
2022-08-02 remove superfluous measurement labels
    [einkpicframe.kicad_pcb]
2022-08-03 Add icon selection, add error handling to sunc, add reacting to button, add battery, add OTA rollback
    [epd.c, io.c, main.c]
2022-08-03 Fix that EPD is upside down in frame, add fw rev to database
2022-08-04 hacky fix for ap mode via button, make base url configurable in menuconfig
    [case.scad]
2022-08-24 Improve low battery handling, add guard for re-downloading rolled-back OTA
    [case.scad]
2022-08-24 Rework to esp-idf 5.0 apis
    [epd.c, io.c, main.c]
2022-08-24 abort before inserting into db on conv error
2022-10-13 Add beerware license
    [case.scad]

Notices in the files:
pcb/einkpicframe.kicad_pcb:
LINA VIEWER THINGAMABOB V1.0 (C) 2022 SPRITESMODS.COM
